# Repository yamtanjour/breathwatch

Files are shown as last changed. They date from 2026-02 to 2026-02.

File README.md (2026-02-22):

# BreathWatch – Portable Air Quality Monitor

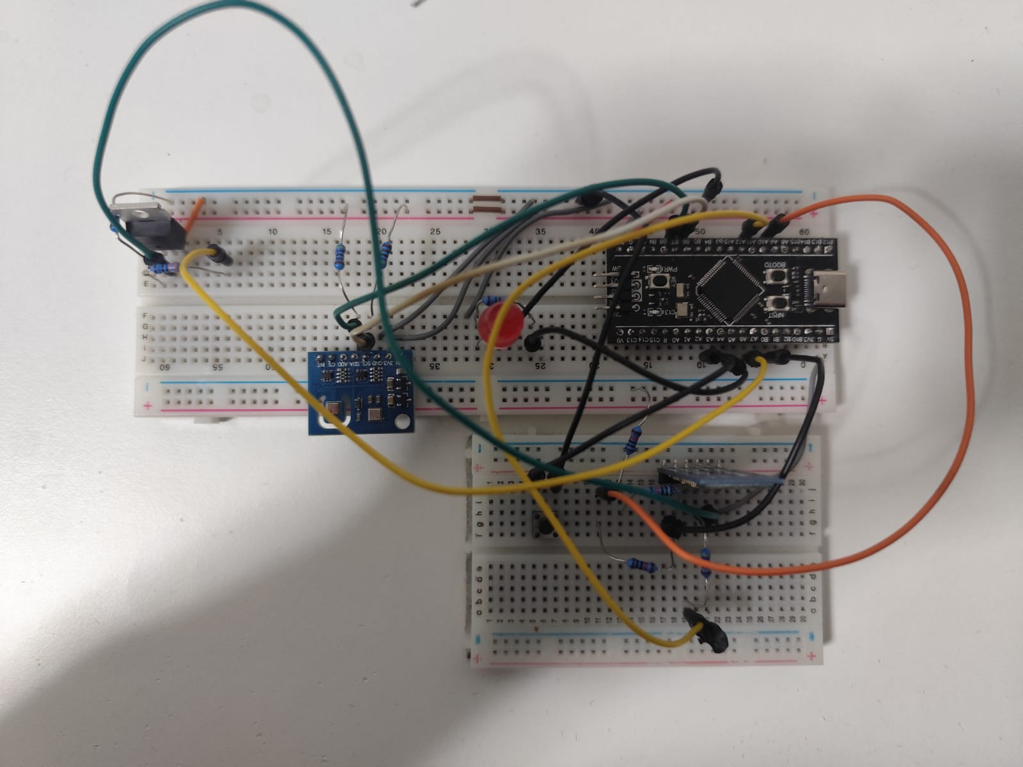
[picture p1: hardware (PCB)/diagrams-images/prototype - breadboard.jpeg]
BreathWatch breadboard prototype


*Prototype using breadboard*

Personal IoT device using STM32 to monitor indoor air quality and send data to a Flutter mobile app via Bluetooth.

## Hardware (PCB Design)

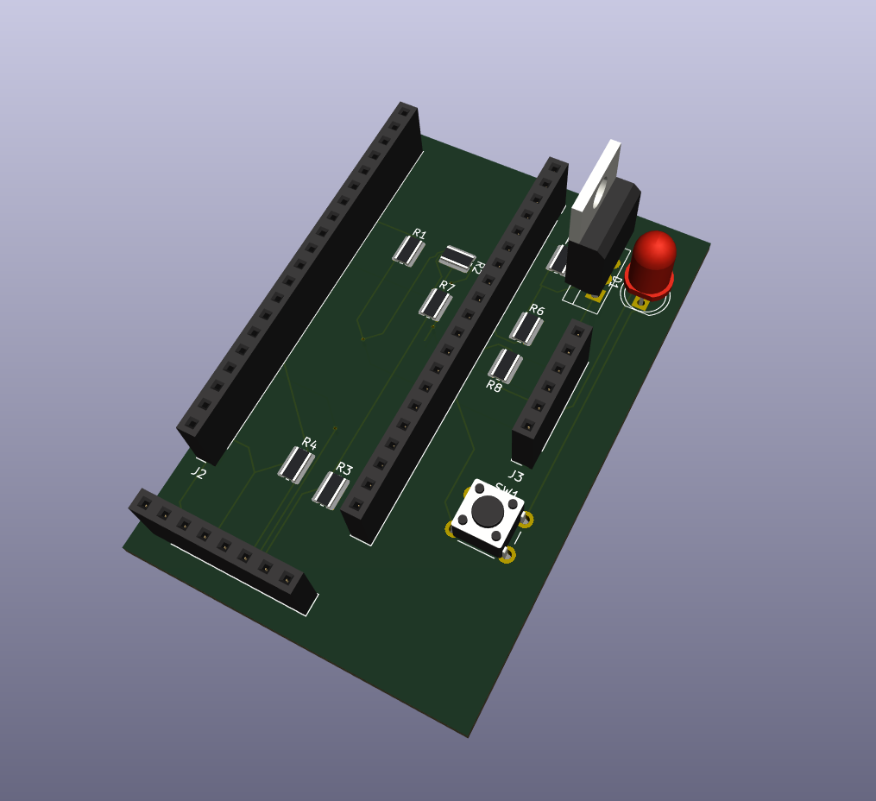
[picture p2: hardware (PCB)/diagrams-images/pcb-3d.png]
Custom PCB 3D render


*3D view of PCB*

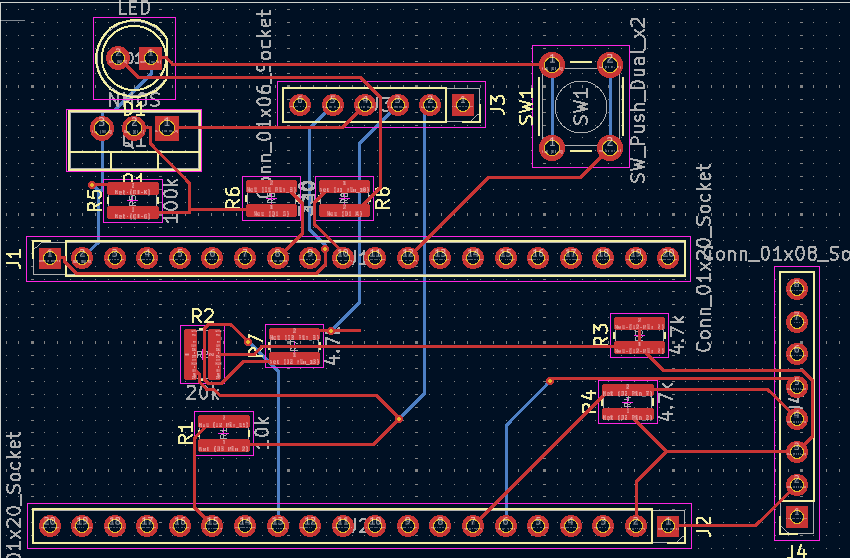
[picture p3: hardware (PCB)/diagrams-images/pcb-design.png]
PCB design


*PCB layout*

## Circuit Overview

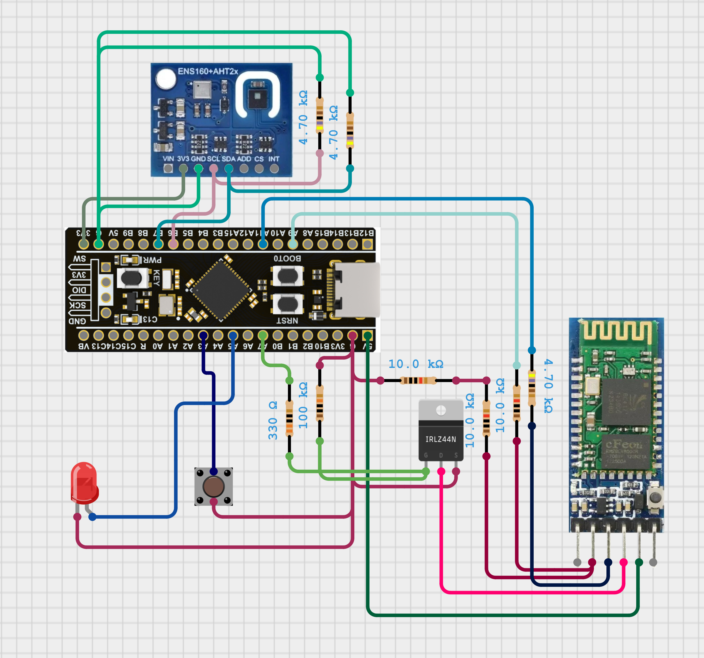
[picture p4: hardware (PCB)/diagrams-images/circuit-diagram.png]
Wiring diagram


*Detailed connections*

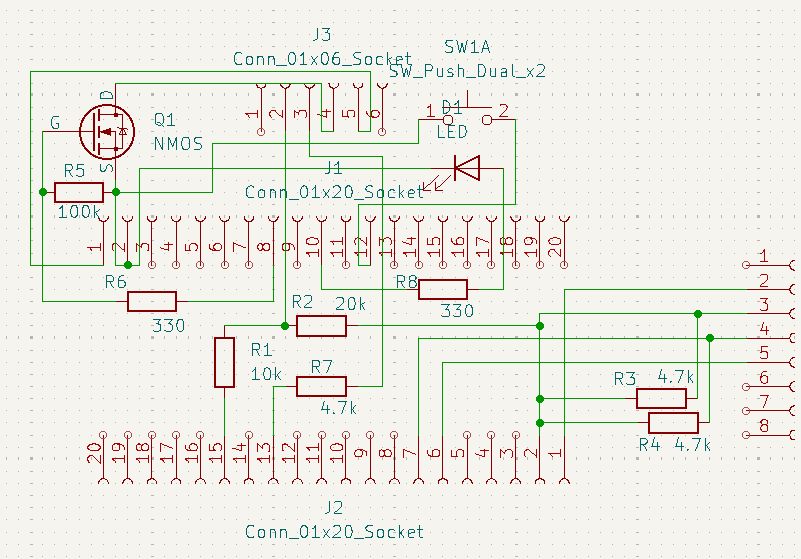
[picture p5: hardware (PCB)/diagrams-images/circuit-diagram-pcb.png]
PCB circuit diagram


*PCB schematic*

## Features

- **Sensors:** ENS160 (eCO2 / TVOC / air quality index) + AHT21 (temperature & humidity) over I2C
- **Bluetooth UART bridge** to Flutter companion app
- **Push button & status LED** control via MOSFET

## Hardware
- STM32F401 microcontroller dev board
- ENS160 air quality sensor
- AHT21 temperature & humidity sensor
- PCB

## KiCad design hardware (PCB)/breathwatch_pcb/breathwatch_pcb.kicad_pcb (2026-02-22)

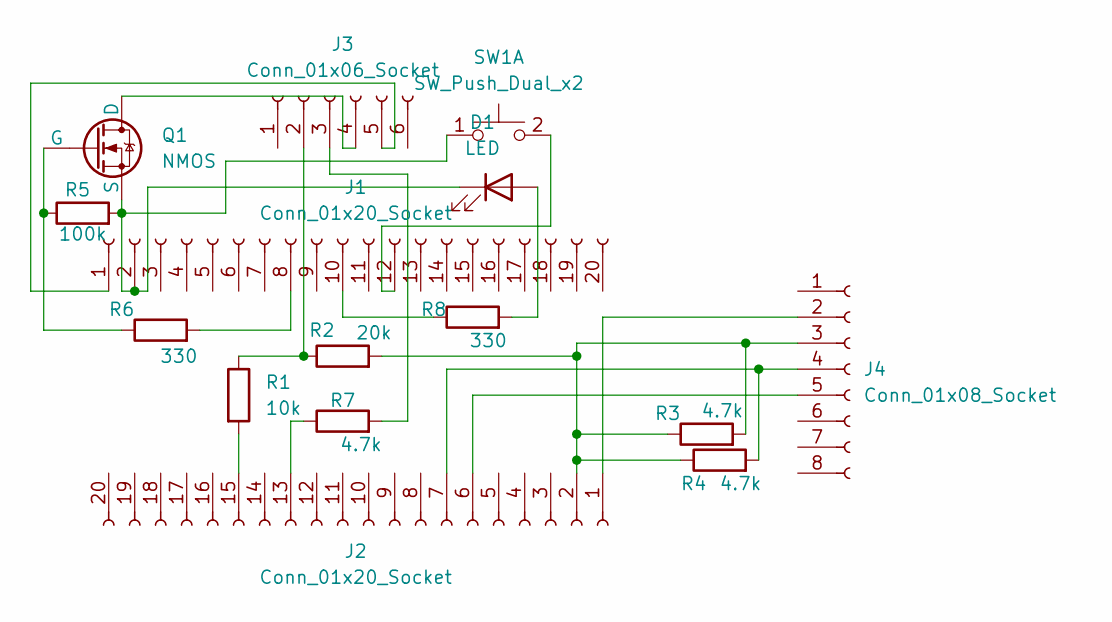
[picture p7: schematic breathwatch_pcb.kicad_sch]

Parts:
D1: LED; LED_D5.0mm
J1, J2: Conn_01x20_Socket; PinSocket_1x20_P2.54mm_Vertical
J3: Conn_01x06_Socket; PinSocket_1x06_P2.54mm_Vertical
J4: Conn_01x08_Socket; PinSocket_1x08_P2.54mm_Vertical
Q1: NMOS; TO-220-3_Vertical
R1: 10k; R_0815_2038Metric
R2: 20k; R_0815_2038Metric
R3, R4, R7: 4.7k; R_0815_2038Metric
R5: 100k; R_0815_2038Metric
R6, R8: 330; R_0815_2038Metric
SW1: SW_Push_Dual_x2; SW_PUSH_6mm_H4.3mm

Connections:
unnamed: D1.2 (A), R8.2
unnamed: D1.1 (K), J1.2, Q1.3 (S), R5.2, SW1.1 (C)
unnamed: J1.1, J3.5
unnamed: J1.8, R6.2
unnamed: J1.10, R8.1
unnamed: J1.12, SW1.2 (D)
unnamed: J2.1, J4.2
unnamed: J2.2, J4.3, R2.2, R3.1, R3.2, R4.1
unnamed: J2.6, J4.5
unnamed: J2.7, J4.4, R4.2
unnamed: J2.13, R7.1
unnamed: J2.15, R1.2
unnamed: J3.2, R1.1, R2.1
unnamed: J3.3, R7.2
unnamed: J3.4, Q1.1 (D)
unnamed: Q1.2 (G), R5.1, R6.1

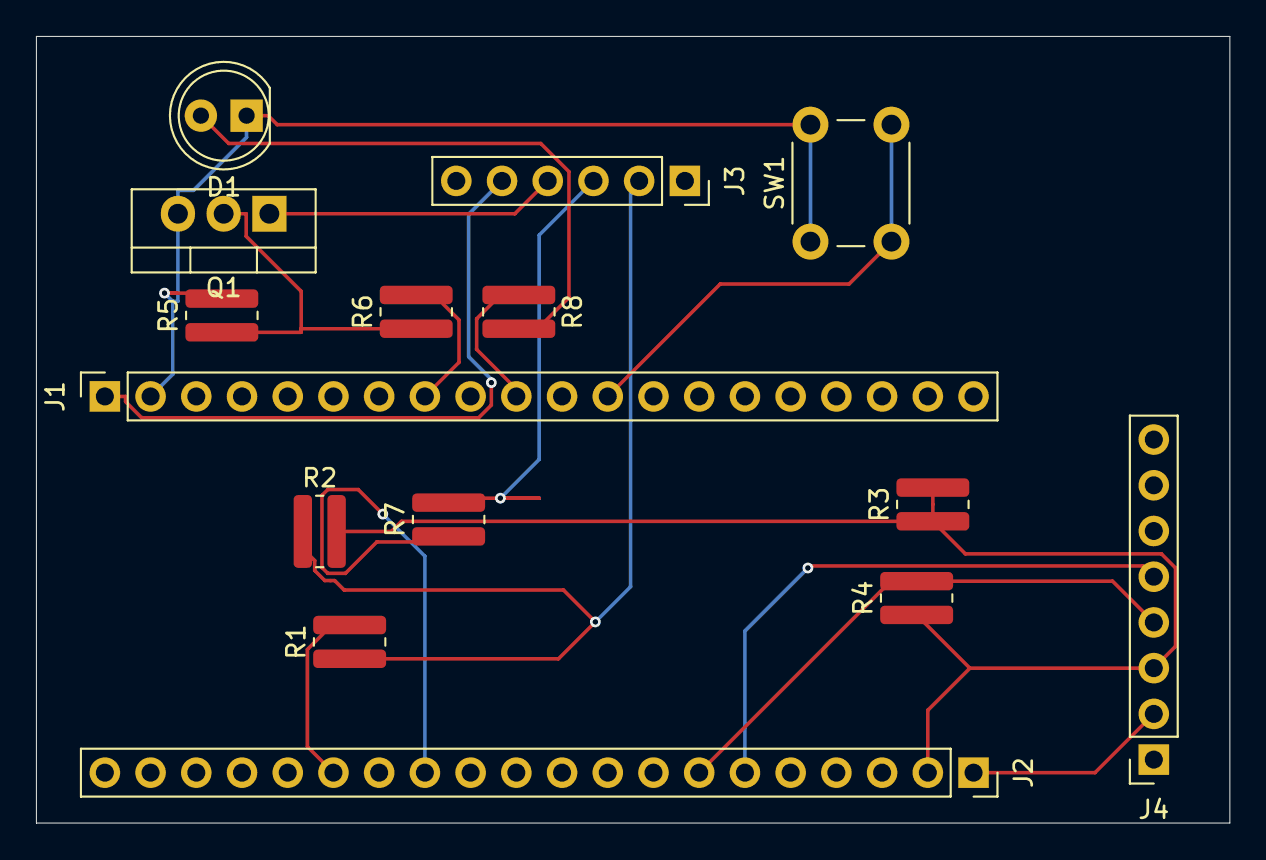
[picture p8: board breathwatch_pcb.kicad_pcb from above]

Board: 2 copper layers, 66.3 x 43.7 mm, 15 parts (0 on the bottom side), 16 nets.

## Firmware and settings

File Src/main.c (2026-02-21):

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
/* Includes ------------------------------------------------------------------*/
#include "main.h"
#include "stm32f4xx_hal_gpio.h"

/* USER CODE BEGIN Includes */
#include <stdint.h>
#include <stdio.h>
#include <string.h>
#include <stdlib.h>


/* USER CODE END Includes */

/* USER CODE BEGIN PTD */
typedef struct {
  float temperature;
  float humidity;
  uint8_t aqi;
  uint16_t tvoc;
  uint16_t eco2;
} SensorData;
/* USER CODE END PTD */

/* USER CODE BEGIN PD */
#define aht21_addr (0x38 << 1) 
#define ens160_addr (0x53 << 1) 
#define ENS160_OPMODE 0x10 
#define ENS160_STATUS 0x20 
#define ENS160_AQI 0x21 
#define ENS160_TVOC_L 0x22 
#define ENS160_ECO2_L 0x24 
#define ENS160_TEMP_IN_L 0x13
#define ENS160_RH_IN_L 0x15
#define LOG_SECTOR_ADDR  0x08020000
#define LOG_SECTOR FLASH_SECTOR_5
#define LOG_RECORD_WORDS ((sizeof(SensorData)+3)/4)
#define LOG_RECORD_BYTES (LOG_RECORD_WORDS*4)
#define LOG_SECTOR_END (LOG_SECTOR_ADDR + 0x20000)
#define LOG_SECTOR_SIZE   0x20000        // 128 KB
#define LOG_SECTOR_END    (LOG_SECTOR_ADDR + (LOG_SECTOR_SIZE * 8 / 10))   // 80%

/* USER CODE END PD */

I2C_HandleTypeDef hi2c1;

RTC_HandleTypeDef hrtc;

UART_HandleTypeDef huart1;

/* USER CODE BEGIN PV */
volatile uint8_t dump_request = 0;
volatile uint8_t bt_connected = 0;

/* USER CODE END PV */

void SystemClock_Config(void);
static void MX_GPIO_Init(void);
static void MX_I2C1_Init(void);
static void MX_USART1_UART_Init(void);
static void MX_RTC_Init(void);
/* USER CODE BEGIN 0 */
void flash_log_sample(uint32_t *ptr, SensorData *s)
{
  HAL_FLASH_Unlock();

  uint32_t *p = (uint32_t*)s;

  for (int i = 0; i < (sizeof(SensorData)+3)/4; i++) {
    HAL_FLASH_Program(FLASH_TYPEPROGRAM_WORD, *ptr, p[i]);
    *ptr += 4;
  }

  HAL_FLASH_Lock();
}
void transmit_flash_data(uint32_t start, uint32_t end)
{
    char line[64];

    while(start < end)
    {
        SensorData *s = (SensorData*)start;

        int ti = (int)(s->temperature * 100);
        int hi = (int)(s->humidity * 100);

        int len = snprintf(line,sizeof(line),
            "%d.%02d,%d.%02d,%d,%d,%d\r\n",
            ti/100, abs(ti%100),
            hi/100, abs(hi%100),
            s->aqi, s->tvoc, s->eco2);

        HAL_UART_Transmit(&huart1,(uint8_t*)line,len,HAL_MAX_DELAY);

        start += LOG_RECORD_BYTES;
    }
}
void erase_flash_sector(void)
{
    FLASH_EraseInitTypeDef erase;
    uint32_t err;

    erase.TypeErase = FLASH_TYPEERASE_SECTORS;
    erase.Sector = LOG_SECTOR;
    erase.NbSectors = 1;
    erase.VoltageRange = FLASH_VOLTAGE_RANGE_3;

    HAL_FLASH_Unlock();
    HAL_FLASHEx_Erase(&erase,&err);
    HAL_FLASH_Lock();
}


/* USER CODE END 0 */

/**
  * @brief  The application entry point.
  * @retval int
  */
int main(void)
{

  /* USER CODE BEGIN 1 */
  uint32_t flash_ptr = LOG_SECTOR_ADDR;
  /* USER CODE END 1 */

  /* MCU Configuration--------------------------------------------------------*/

  /* Reset of all peripherals, Initializes the Flash interface and the Systick. */
  HAL_Init();

  /* Configure the system clock */
  SystemClock_Config();

  /* USER CODE BEGIN SysInit */
  while(flash_ptr < LOG_SECTOR_END &&
      *(uint32_t*)flash_ptr != 0xFFFFFFFF)
  {
    flash_ptr += 4;
  }
  /* USER CODE END SysInit */

  /* Initialize all configured peripherals */
  MX_GPIO_Init();
  MX_I2C1_Init();
  MX_USART1_UART_Init();
  MX_RTC_Init();
  /* Infinite loop */
  /* USER CODE BEGIN WHILE */

  uint8_t opmode[2] = {ENS160_OPMODE, 0x02};
  HAL_I2C_Master_Transmit(&hi2c1, ens160_addr, opmode, 2, 100);
  volatile uint8_t  aqi_g = 0;
  volatile uint16_t tvoc_g = 0;
  volatile uint16_t eco2_g = 0;
  volatile uint8_t  status_dbg = 0;
  HAL_GPIO_WritePin(GPIOA, GPIO_PIN_5, GPIO_PIN_RESET);
  HAL_Delay(1000);

  while (1) {
    if(dump_request) {
      dump_request = 0;
      HAL_GPIO_WritePin(GPIOA, GPIO_PIN_7, GPIO_PIN_SET);
      HAL_Delay(200);
      uint32_t t0 = HAL_GetTick();
      bt_connected = 0;

      // wait up to 45s for BT STATE interrupt
      while(HAL_GetTick() - t0 < 45000)
      {
        if(bt_connected)
          break;
      }
      if(bt_connected)
      {
        transmit_flash_data(LOG_SECTOR_ADDR, flash_ptr);
        HAL_UART_Transmit(&huart1, (uint8_t*)"END\r\n", 5, HAL_MAX_DELAY);
        erase_flash_sector();
        flash_ptr = LOG_SECTOR_ADDR;
        for(int i=0;i<3;i++) {
        HAL_GPIO_TogglePin(GPIOA, GPIO_PIN_5);
        HAL_Delay(200);
        HAL_GPIO_TogglePin(GPIOA, GPIO_PIN_5);
        HAL_Delay(200);
        }
        HAL_GPIO_WritePin(GPIOA, GPIO_PIN_5, GPIO_PIN_RESET);
      }
      HAL_GPIO_WritePin(GPIOA, GPIO_PIN_7, GPIO_PIN_RESET);
      continue;
    }
    uint8_t cmd[3] = {0xAC, 0x33, 0x00};
    HAL_I2C_Master_Transmit(&hi2c1, aht21_addr, cmd, 3, 100);
    HAL_Delay(150);
    uint8_t data[6];
    HAL_I2C_Master_Receive(&hi2c1, aht21_addr, data, 6, 100);
    uint32_t raw_hum = ((uint32_t)data[1] << 12) | ((uint32_t)data[2] << 4) | ((uint32_t)data[3] >> 4);
    uint32_t raw_temp = ((uint32_t)(data[3] & 0x0F) << 16) | ((uint32_t)data[4] << 8) | data[5];
    float hum = (raw_hum * 100.0f) / 1048576.0f;
    float temp = ((raw_temp * 200.0f) / 1048576.0f) - 50.0f;
    HAL_Delay(150);
    uint16_t temp_in = (uint16_t)(temp * 64.0f);
    uint16_t hum_in = (uint16_t)(hum * 512.0f);

    uint8_t temp_ens[3] = {ENS160_TEMP_IN_L, (uint8_t)(temp_in & 0xFF), (uint8_t)(temp_in >> 8)};
    uint8_t hum_ens[3] = {ENS160_RH_IN_L, (uint8_t)(hum_in & 0xFF), (uint8_t)(hum_in >> 8)};
    HAL_I2C_Master_Transmit(&hi2c1, ens160_addr, temp_ens, 3, HAL_MAX_DELAY);
    HAL_I2C_Master_Transmit(&hi2c1, ens160_addr, hum_ens, 3, HAL_MAX_DELAY);

    uint8_t reg = ENS160_STATUS;
    uint8_t status;

    HAL_I2C_Master_Transmit(&hi2c1, ens160_addr, &reg, 1, HAL_MAX_DELAY);
    HAL_I2C_Master_Receive(&hi2c1, ens160_addr, &status, 1, HAL_MAX_DELAY);
    status_dbg = status;
    if (status != 0) {
      volatile uint8_t aqi;
      uint8_t buf[2];

      reg = ENS160_AQI;
      HAL_I2C_Master_Transmit(&hi2c1, ens160_addr, &reg, 1, HAL_MAX_DELAY);
      HAL_I2C_Master_Receive(&hi2c1, ens160_addr, &aqi, 1, HAL_MAX_DELAY);

      reg = ENS160_TVOC_L;
      HAL_I2C_Master_Transmit(&hi2c1, ens160_addr, &reg, 1, HAL_MAX_DELAY);
      HAL_I2C_Master_Receive(&hi2c1, ens160_addr, buf, 2, HAL_MAX_DELAY);
      volatile uint16_t tvoc = (uint16_t)buf[0] | ((uint16_t)(buf[1]) << 8);

      reg = ENS160_ECO2_L;
      HAL_I2C_Master_Transmit(&hi2c1, ens160_addr, &reg, 1, HAL_MAX_DELAY);
      HAL_I2C_Master_Receive(&hi2c1, ens160_addr, buf, 2, HAL_MAX_DELAY);
      volatile uint16_t eco2 = (uint16_t)buf[0] | ((uint16_t)(buf[1]) << 8);
      aqi_g = aqi;
      tvoc_g = tvoc;
      eco2_g = eco2;

      SensorData sample;

      sample.temperature = temp;
      sample.humidity = hum;
      sample.aqi = aqi;
      sample.tvoc = tvoc;
      sample.eco2 = eco2;
      if(flash_ptr + LOG_RECORD_BYTES <= LOG_SECTOR_END){
        flash_log_sample(&flash_ptr, &sample);
        HAL_GPIO_TogglePin(GPIOA, GPIO_PIN_5);
        HAL_Delay(1000);
        HAL_GPIO_TogglePin(GPIOA, GPIO_PIN_5);
      }
      int temp_i = (int)(temp * 100);
      int hum_i = (int)(hum * 100);

      char line[64];

      int len = snprintf(line, sizeof(line),
         "%d.%02d,%d.%02d,%d,%d,%d\r\n",
         temp_i/100, abs(temp_i%100),
         hum_i/100, abs(hum_i%100),
         aqi, tvoc, eco2);
      
      HAL_GPIO_WritePin(GPIOA, GPIO_PIN_5, GPIO_PIN_RESET);
      HAL_Delay(2000);
      HAL_Delay(10000);


    }
  }
}
    /* USER CODE END WHILE */

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
/* USER CODE BEGIN 4 */
void HAL_GPIO_EXTI_Callback(uint16_t GPIO_Pin)
{
    if(GPIO_Pin == GPIO_PIN_3)
    {
        dump_request = 1;
        HAL_GPIO_WritePin(GPIOA, GPIO_PIN_5, GPIO_PIN_SET);
    }
    if(GPIO_Pin == GPIO_PIN_1)   // Bluetooth STATE
    {
        bt_connected = 1;
        HAL_GPIO_TogglePin(GPIOA, GPIO_PIN_5);
    }

}

/* USER CODE END 4 */
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


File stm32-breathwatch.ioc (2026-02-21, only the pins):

Mcu.UserName=STM32F401RCTx
PA10.Signal=USART1_RX
PA13.Signal=SYS_JTMS-SWDIO
PA14.Signal=SYS_JTCK-SWCLK
PA3.Signal=GPXTI3
PA5.Signal=GPIO_Output
PA7.Signal=GPIO_Output
PA9.Signal=USART1_TX
PB1.Signal=GPXTI1
PB6.Signal=I2C1_SCL
PB7.Signal=I2C1_SDA

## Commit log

2026-02-21 changed from ESP32 to STM32
    [breathwatch_pcb-B_Cu.gbr, breathwatch_pcb-B_Mask.gbr, breathwatch_pcb-B_Paste.gbr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]
2026-02-22 PCB Design
    [breathwatch_pcb.kicad_pcb, breathwatch_pcb.kicad_sch]

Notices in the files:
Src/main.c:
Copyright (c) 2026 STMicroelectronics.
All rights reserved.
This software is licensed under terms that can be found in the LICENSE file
